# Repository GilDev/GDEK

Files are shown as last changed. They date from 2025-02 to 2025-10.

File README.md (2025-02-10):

# GDEK: Your first ergonomic keyboard

Want to try ergonomic keyboards? Don’t know where to start? Don’t want to break the bank yet before knowing what you really want? This may be the keyboard for you.

I created this keyboard following [a little crowdfunding campaign](https://fr.ulule.com/clavier-ergonomique-gildev/) I ran for people that were interested in improving their typing comfort but didn’t want to spend too much money on a device they might not like or would like some feature. This keyboard was entirely designed from scratch, after experimenting for some years with a TypeMatrix 2030, a original X-Bows (Kickstarter edition) and a personnal variant of the Sofle Choc RGB.

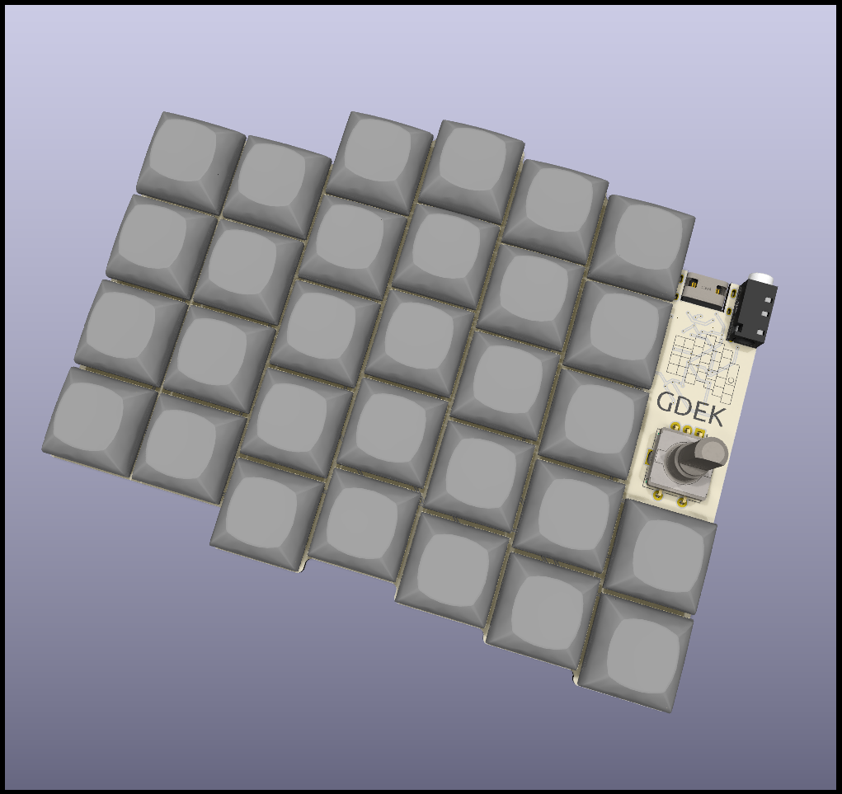
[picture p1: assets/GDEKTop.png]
GDEKTop


## Features

* **4×6 matrix**: you don’t risk missing anything, you can always disable things later on in software to see if missing that top number row would work for you. You can even type in [Bépo](https://bepo.fr/) with minimal modifications!
* **Split**: optimal hands placement, with room in the middle for a trackball or Magic Trackpad, and a simple audio cable to connect the two halves with connectors that won’t mechanically constrain your cable
* **Compact**: despite the “full” matrix, it’s easy to bring it along
* **5 keys thumb cluster**: enough for anything you could imagine
* **Supports MX, Kailh Choc and Gateron KS-33 low-profile switches**: I personnaly use KS-33 switches as they’re low-profile, cheap and support standard MX-compatible keycaps
* **Per-key RGB**: more than just for looks, they can indicate what some keys do, which layer you’re on, etc.
* **Encoder**: you may think it’s a gimmick, but at least you can try it and see if you like it. I love it to scroll, move the cursor, control volume, etc.
* **RP2040**: a very cool and powerful microcontroller that will support any features you could image without breaking a sweat. Easy to flash: it appears like a USB drive that you can drag the firmware onto
* **QMK firmware with VIA support**: easily configurable and customizable via a web app
* **Assembly-friendly**: send the PCB to be assembled and just solder the switches, encoders and audio TRS jack (pretty easy)
* **Open-source**: you can modify the design to your liking, design a case and so on

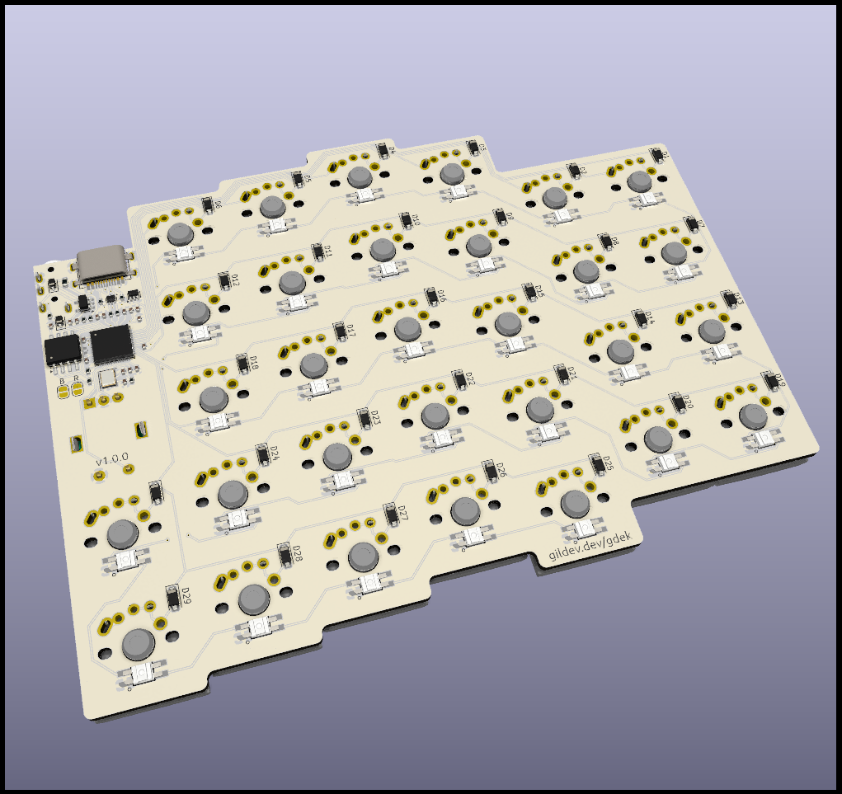
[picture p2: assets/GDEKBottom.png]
GDEKBottom


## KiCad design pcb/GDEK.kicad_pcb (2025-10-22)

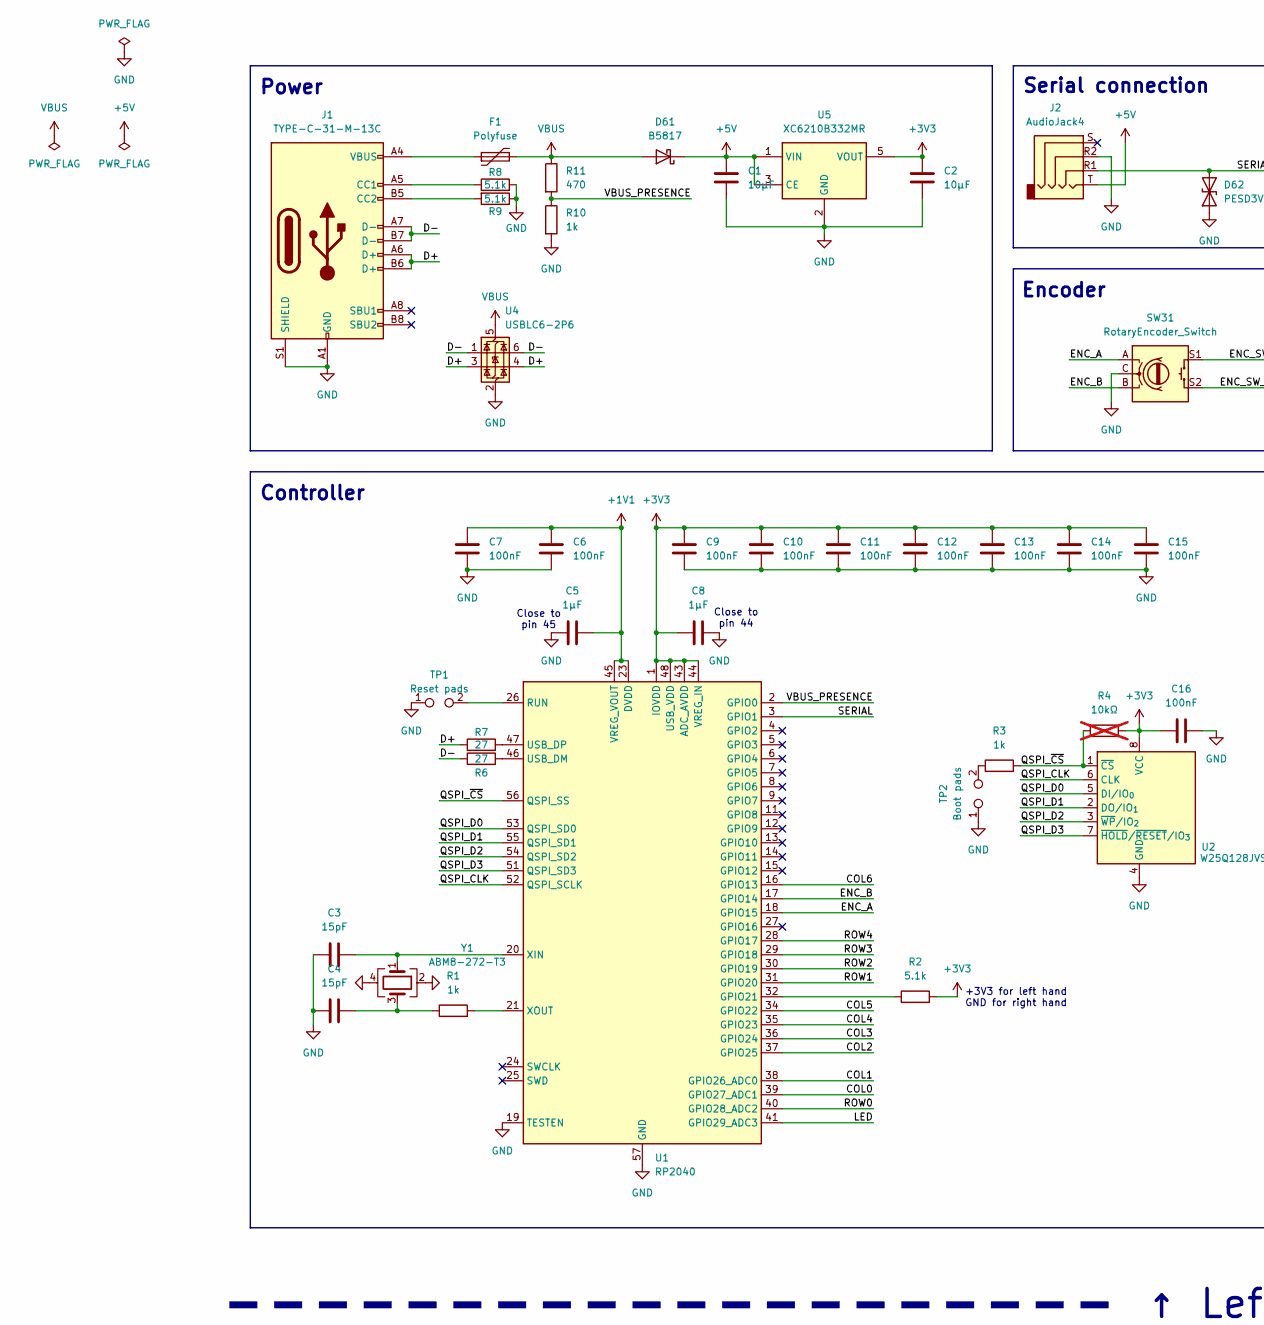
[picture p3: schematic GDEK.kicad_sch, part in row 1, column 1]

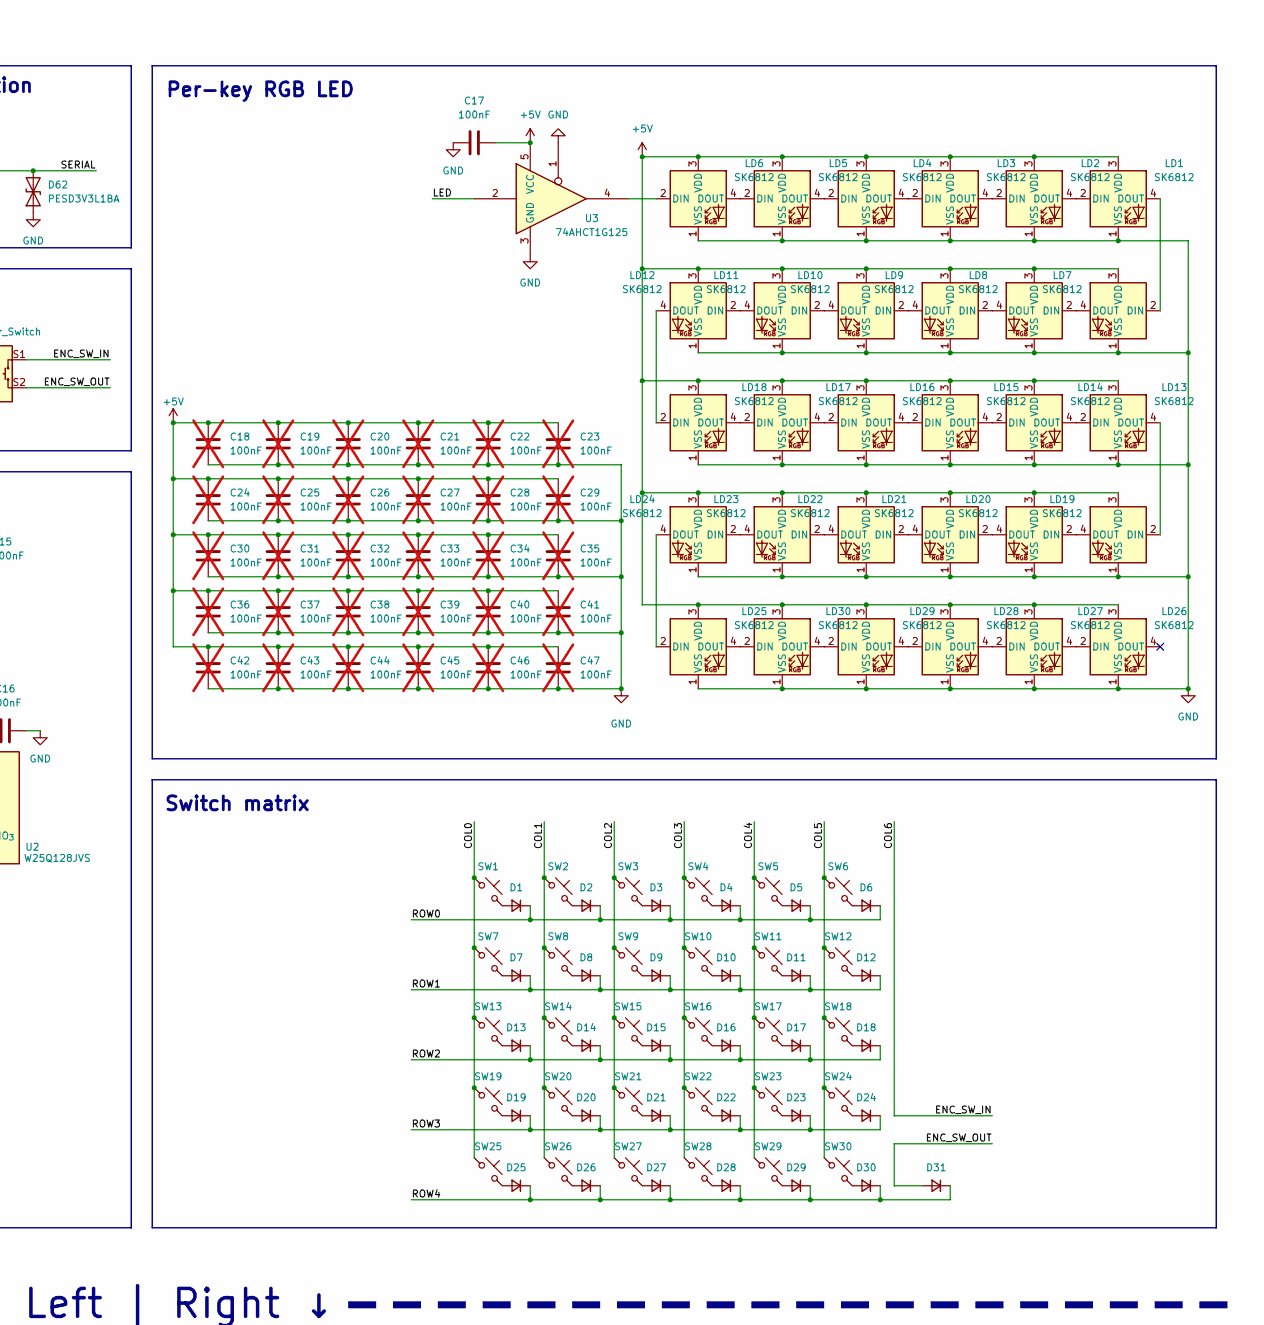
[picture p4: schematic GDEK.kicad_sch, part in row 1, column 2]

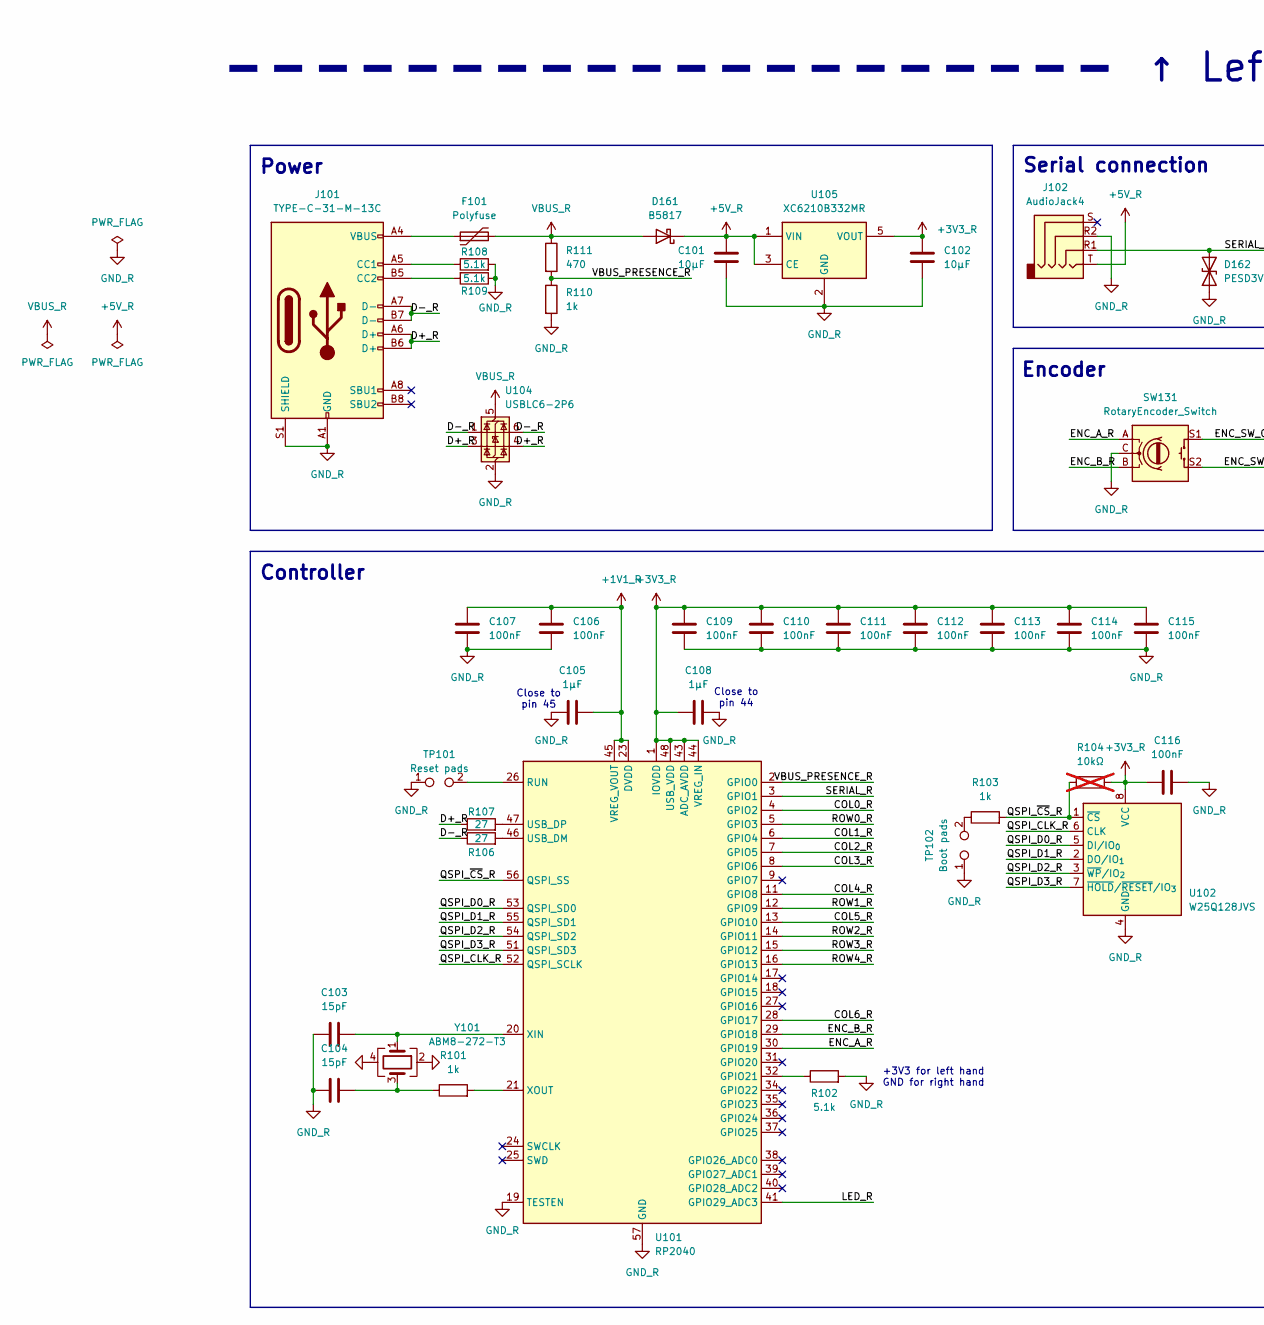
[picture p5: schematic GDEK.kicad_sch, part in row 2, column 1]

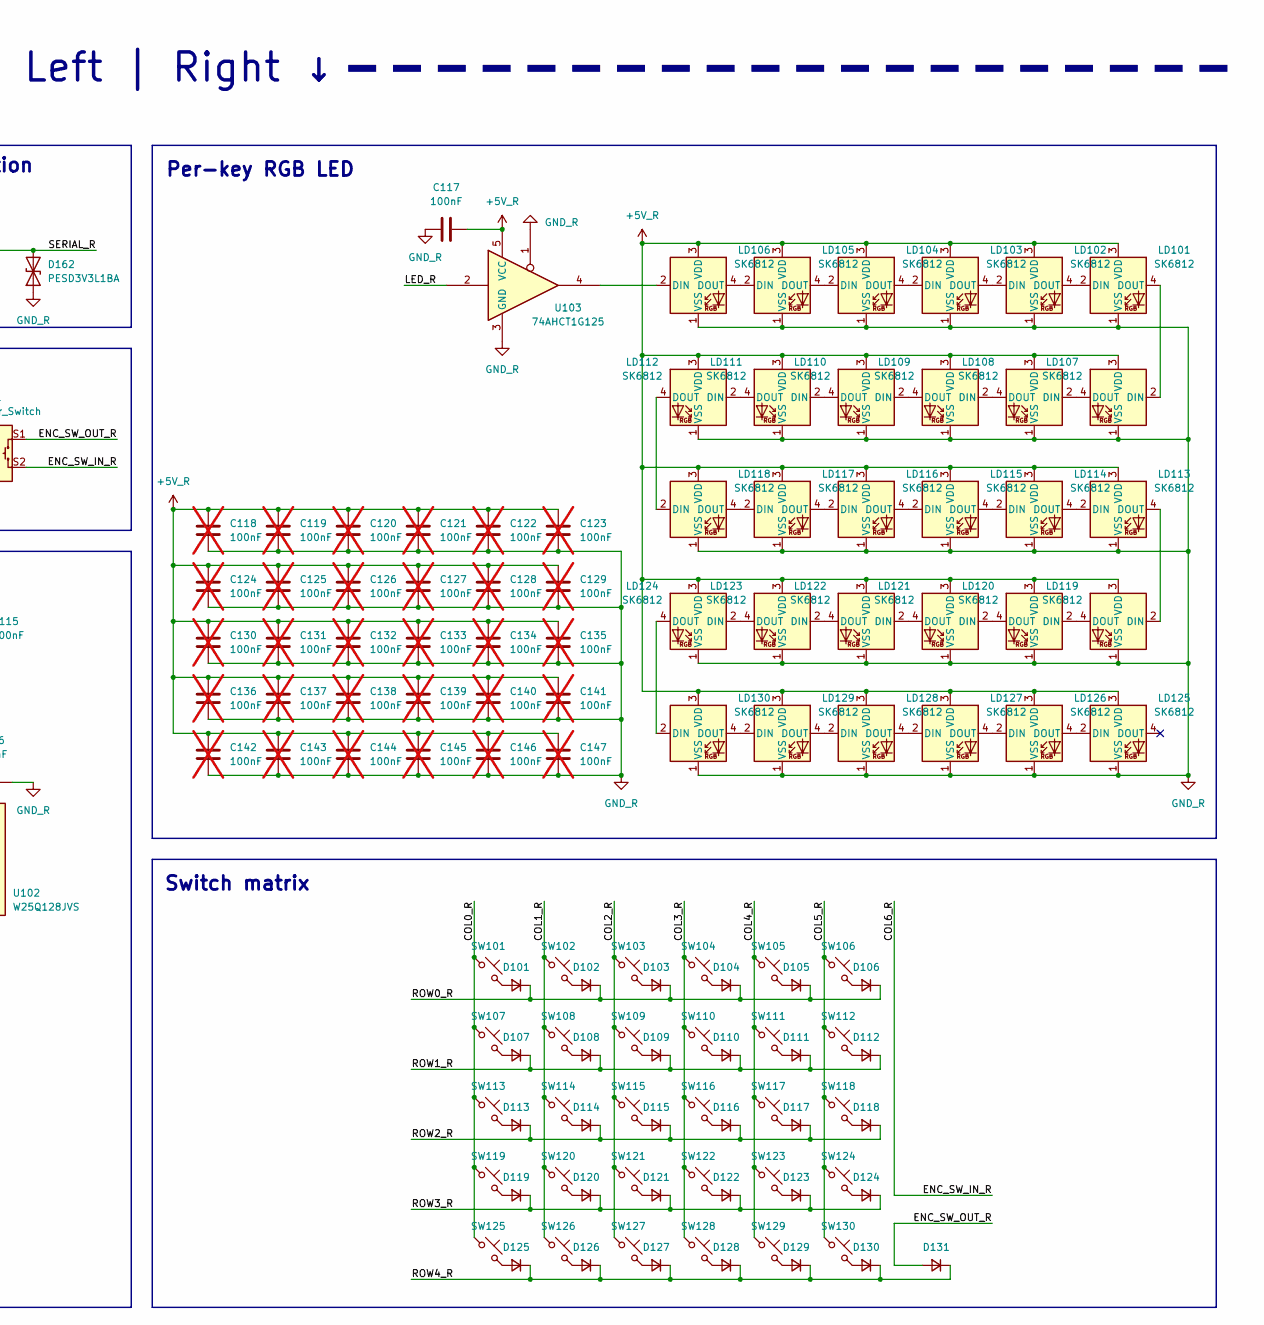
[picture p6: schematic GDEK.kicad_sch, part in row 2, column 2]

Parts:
C1, C2, C101, C102: 10µF; C_0402_1005Metric; LCSC C15525
C3, C4, C103, C104: 15pF; C_0402_1005Metric; LCSC C1548
C5, C8, C105, C108: 1µF; C_0402_1005Metric; LCSC C52923
C6, C7, C9, C10, C11, C12, C13, C14, C15, C16, C17, C106, C107, C109, C110, C111, C112, C113, C114, C115, C116, C117: 100nF; C_0402_1005Metric; LCSC C1525
C18, C19, C20, C21, C22, C23, C24, C25, C26, C27, C28, C29, C30, C31, C32, C33, C34, C35, C36, C37, C38, C39, C40, C41, C42, C43, C44, C45, C46, C47, C118, C119, C120, C121, C122, C123, C124, C125, C126, C127, C128, C129, C130, C131, C132, C133, C134, C135, C136, C137, C138, C139, C140, C141, C142, C143, C144, C145, C146, C147: 100nF; C_0402_1005Metric; LCSC C1525; not fitted
D1, D2, D3, D4, D5, D6, D7, D8, D9, D10, D11, D12, D13, D14, D15, D16, D17, D18, D19, D20, D21, D22, D23, D24, D25, D26, D27, D28, D29, D30, D31, D101, D102, D103, D104, D105, D106, D107, D108, D109, D110, D111, D112, D113, D114, D115, D116, D117, D118, D119, D120, D121, D122, D123, D124, D125, D126, D127, D128, D129, D130, D131: D_Small; D_SOD-123; LCSC C7420318
D61, D161: B5817; D_SOD-323; LCSC C123899
D62, D162: PESD3V3L1BA; D_SOD-323; LCSC C2827682
F1, F101: Polyfuse; Fuse_0603_1608Metric; LCSC C69679
J1, J101: TYPE-C-31-M-13C; USB_C_Receptacle_HRO_TYPE-C-31-M-13B; LCSC C2848620
J2, J102: AudioJack4; AUDIO-TH_PJ-320A-4P-DIP; LCSC C18185602
LD1, LD2, LD3, LD4, LD5, LD6, LD7, LD8, LD9, LD10, LD11, LD12, LD13, LD14, LD15, LD16, LD17, LD18, LD19, LD20, LD21, LD22, LD23, LD24, LD25, LD26, LD27, LD28, LD29, LD30, LD101, LD102, LD103, LD104, LD105, LD106, LD107, LD108, LD109, LD110, LD111, LD112, LD113, LD114, LD115, LD116, LD117, LD118, LD119, LD120, LD121, LD122, LD123, LD124, LD125, LD126, LD127, LD128, LD129, LD130: SK6812; SK6812MINIE; LCSC C5149201
R1, R3, R10, R101, R103, R110: 1k; R_0402_1005Metric; LCSC C11702
R2, R8, R9, R102, R108, R109: 5.1k; R_0402_1005Metric; LCSC C25905
R4, R104: 10kΩ; R_0402_1005Metric; not fitted
R6, R7, R106, R107: 27; R_0402_1005Metric; LCSC C25100
R11, R111: 470; R_0402_1005Metric; LCSC C25117
SW1, SW2, SW3, SW4, SW5, SW6, SW7, SW8, SW9, SW10, SW11, SW12, SW13, SW14, SW15, SW16, SW17, SW18, SW19, SW20, SW21, SW22, SW23, SW24, SW25, SW26, SW27, SW28, SW29, SW30, SW101, SW102, SW103, SW104, SW105, SW106, SW107, SW108, SW109, SW110, SW111, SW112, SW113, SW114, SW115, SW116, SW117, SW118, SW119, SW120, SW121, SW122, SW123, SW124, SW125, SW126, SW127, SW128, SW129, SW130: SW_Push_45deg; MX+KailhChoc+GateronKS_Tight
SW31, SW131: RotaryEncoder_Switch; RotaryEncoder_Alps_EC11E-Switch_Vertical_H20mm
TP1, TP101: Reset pads; SolderJumper-2_P1.3mm_Open_RoundedPad1.0x1.5mm
TP2, TP102: Boot pads; SolderJumper-2_P1.3mm_Open_RoundedPad1.0x1.5mm
U1, U101: RP2040; QFN-56-1EP_7x7mm_P0.4mm_EP3.2x3.2mm; LCSC C2040
U2, U102: W25Q128JVS; SOIC-8_5.3x5.3mm_P1.27mm; LCSC C97521
U3, U103: 74AHCT1G125; SOT-353_SC-70-5; LCSC C151417
U4, U104: USBLC6-2P6; SOT-666; LCSC C2827693
U5, U105: XC6210B332MR; SOT-23-5
Y1, Y101: ABM8-272-T3; Crystal_SMD_3225-4Pin_3.2x2.5mm; LCSC C20625731

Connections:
+1V1: C5.2, C6.1, C7.1, U1.23 (DVDD), U1.45 (VREG_VOUT), U1.50 (DVDD)
+1V1_R: C105.2, C106.1, C107.1, U101.23 (DVDD), U101.45 (VREG_VOUT), U101.50 (DVDD)
+3V3: C2.1, C8.1, C9.1, C10.1, C11.1, C12.1, C13.1, C14.1, C15.1, C16.1, R2.2, R4.2, U1.1 (IOVDD), U1.10 (IOVDD), U1.22 (IOVDD), U1.33 (IOVDD), U1.42 (IOVDD), U1.43 (ADC_AVDD), U1.44 (VREG_IN), U1.48 (USB_VDD), U1.49 (IOVDD), U2.8 (VCC), U5.5 (VOUT)
+3V3_R: C102.1, C108.1, C109.1, C110.1, C111.1, C112.1, C113.1, C114.1, C115.1, C116.1, R104.1, U101.1 (IOVDD), U101.10 (IOVDD), U101.22 (IOVDD), U101.33 (IOVDD), U101.42 (IOVDD), U101.43 (ADC_AVDD), U101.44 (VREG_IN), U101.48 (USB_VDD), U101.49 (IOVDD), U102.8 (VCC), U105.5 (VOUT)
+5V: C1.1, C17.2, C18.2, C19.2, C20.2, C21.2, C22.2, C23.2, C24.2, C25.2, C26.2, C27.2, C28.2, C29.2, C30.2, C31.2, C32.2, C33.2, C34.2, C35.2, C36.2, C37.2, C38.2, C39.2, C40.2, C41.2, C42.2, C43.2, C44.2, C45.2, C46.2, C47.2, D61.1 (K), J2.T, LD1.3 (VDD), LD2.3 (VDD), LD3.3 (VDD), LD4.3 (VDD), LD5.3 (VDD), LD6.3 (VDD), LD7.3 (VDD), LD8.3 (VDD), LD9.3 (VDD), LD10.3 (VDD), LD11.3 (VDD), LD12.3 (VDD), LD13.3 (VDD), LD14.3 (VDD), LD15.3 (VDD), LD16.3 (VDD), LD17.3 (VDD), LD18.3 (VDD), LD19.3 (VDD), LD20.3 (VDD), LD21.3 (VDD), LD22.3 (VDD), LD23.3 (VDD), LD24.3 (VDD), LD25.3 (VDD), LD26.3 (VDD), LD27.3 (VDD), LD28.3 (VDD), LD29.3 (VDD), LD30.3 (VDD), U3.5 (VCC), U5.1 (VIN), U5.3 (CE)
+5V_R: C101.1, C117.2, C118.2, C119.2, C120.2, C121.2, C122.2, C123.2, C124.2, C125.2, C126.2, C127.2, C128.2, C129.2, C130.2, C131.2, C132.2, C133.2, C134.2, C135.2, C136.2, C137.2, C138.2, C139.2, C140.2, C141.2, C142.2, C143.2, C144.2, C145.2, C146.2, C147.2, D161.1 (K), J102.T, LD101.3 (VDD), LD102.3 (VDD), LD103.3 (VDD), LD104.3 (VDD), LD105.3 (VDD), LD106.3 (VDD), LD107.3 (VDD), LD108.3 (VDD), LD109.3 (VDD), LD110.3 (VDD), LD111.3 (VDD), LD112.3 (VDD), LD113.3 (VDD), LD114.3 (VDD), LD115.3 (VDD), LD116.3 (VDD), LD117.3 (VDD), LD118.3 (VDD), LD119.3 (VDD), LD120.3 (VDD), LD121.3 (VDD), LD122.3 (VDD), LD123.3 (VDD), LD124.3 (VDD), LD125.3 (VDD), LD126.3 (VDD), LD127.3 (VDD), LD128.3 (VDD), LD129.3 (VDD), LD130.3 (VDD), U103.5 (VCC), U105.1 (VIN), U105.3 (CE)
/COL0: SW1.1, SW7.1, SW13.1, SW19.1, SW25.1, U1.39 (GPIO27_ADC1)
/COL0_R: SW101.1, SW107.1, SW113.1, SW119.1, SW125.1, U101.4 (GPIO2)
/COL1: SW2.1, SW8.1, SW14.1, SW20.1, SW26.1, U1.38 (GPIO26_ADC0)
/COL1_R: SW102.1, SW108.1, SW114.1, SW120.1, SW126.1, U101.6 (GPIO4)
/COL2: SW3.1, SW9.1, SW15.1, SW21.1, SW27.1, U1.37 (GPIO25)
/COL2_R: SW103.1, SW109.1, SW115.1, SW121.1, SW127.1, U101.7 (GPIO5)
/COL3: SW4.1, SW10.1, SW16.1, SW22.1, SW28.1, U1.36 (GPIO24)
/COL3_R: SW104.1, SW110.1, SW116.1, SW122.1, SW128.1, U101.8 (GPIO6)
/COL4: SW5.1, SW11.1, SW17.1, SW23.1, SW29.1, U1.35 (GPIO23)
/COL4_R: SW105.1, SW111.1, SW117.1, SW123.1, SW129.1, U101.11 (GPIO8)
/COL5: SW6.1, SW12.1, SW18.1, SW24.1, SW30.1, U1.34 (GPIO22)
/COL5_R: SW106.1, SW112.1, SW118.1, SW124.1, SW130.1, U101.13 (GPIO10)
/COL6: SW31.S1, U1.16 (GPIO13)
/COL6_R: SW131.S2, U101.28 (GPIO17)
/D+: J1.A6 (D+), J1.B6 (D+), R7.1, U4.3 (I/O2), U4.4 (I/O2)
/D+_R: J101.A6 (D+), J101.B6 (D+), R107.1, U104.3 (I/O2), U104.4 (I/O2)
/D-: J1.A7 (D-), J1.B7 (D-), R6.1, U4.1 (I/O1), U4.6 (I/O1)
/D-_R: J101.A7 (D-), J101.B7 (D-), R106.1, U104.1 (I/O1), U104.6 (I/O1)
/ENC_A: SW31.A, U1.18 (GPIO15)
/ENC_A_R: SW131.A, U101.30 (GPIO19)
/ENC_B: SW31.B, U1.17 (GPIO14)
/ENC_B_R: SW131.B, U101.29 (GPIO18)
/ENC_SW_OUT: D31.2 (A), SW31.S2
/ENC_SW_OUT_R: D131.2 (A), SW131.S1
/LED: U1.41 (GPIO29_ADC3), U3.2
/LED_R: U101.41 (GPIO29_ADC3), U103.2
/QSPI_CLK: U1.52 (QSPI_SCLK), U2.6 (CLK)
/QSPI_CLK_R: U101.52 (QSPI_SCLK), U102.6 (CLK)
/QSPI_D0: U1.53 (QSPI_SD0), U2.5 (DI/IO_{0})
/QSPI_D0_R: U101.53 (QSPI_SD0), U102.5 (DI/IO_{0})
/QSPI_D1: U1.55 (QSPI_SD1), U2.2 (DO/IO_{1})
/QSPI_D1_R: U101.55 (QSPI_SD1), U102.2 (DO/IO_{1})
/QSPI_D2: U1.54 (QSPI_SD2), U2.3 (~WP/IO_{2})
/QSPI_D2_R: U101.54 (QSPI_SD2), U102.3 (~WP/IO_{2})
/QSPI_D3: U1.51 (QSPI_SD3), U2.7 (~HOLD/~RESET/IO_{3})
/QSPI_D3_R: U101.51 (QSPI_SD3), U102.7 (~HOLD/~RESET/IO_{3})
/QSPI_~CS: R3.2, R4.1, U1.56 (QSPI_SS), U2.1 (~CS)
/QSPI_~CS_R: R103.2, R104.2, U101.56 (QSPI_SS), U102.1 (~CS)
/ROW0: D1.1 (K), D2.1 (K), D3.1 (K), D4.1 (K), D5.1 (K), D6.1 (K), U1.40 (GPIO28_ADC2)
/ROW0_R: D101.1 (K), D102.1 (K), D103.1 (K), D104.1 (K), D105.1 (K), D106.1 (K), U101.5 (GPIO3)
/ROW1: D7.1 (K), D8.1 (K), D9.1 (K), D10.1 (K), D11.1 (K), D12.1 (K), U1.31 (GPIO20)
/ROW1_R: D107.1 (K), D108.1 (K), D109.1 (K), D110.1 (K), D111.1 (K), D112.1 (K), U101.12 (GPIO9)
/ROW2: D13.1 (K), D14.1 (K), D15.1 (K), D16.1 (K), D17.1 (K), D18.1 (K), U1.30 (GPIO19)
/ROW2_R: D113.1 (K), D114.1 (K), D115.1 (K), D116.1 (K), D117.1 (K), D118.1 (K), U101.14 (GPIO11)
/ROW3: D19.1 (K), D20.1 (K), D21.1 (K), D22.1 (K), D23.1 (K), D24.1 (K), U1.29 (GPIO18)
/ROW3_R: D119.1 (K), D120.1 (K), D121.1 (K), D122.1 (K), D123.1 (K), D124.1 (K), U101.15 (GPIO12)
/ROW4: D25.1 (K), D26.1 (K), D27.1 (K), D28.1 (K), D29.1 (K), D30.1 (K), D31.1 (K), U1.28 (GPIO17)
/ROW4_R: D125.1 (K), D126.1 (K), D127.1 (K), D128.1 (K), D129.1 (K), D130.1 (K), D131.1 (K), U101.16 (GPIO13)
/SERIAL: D62.2 (A2), J2.R1, U1.3 (GPIO1)
/SERIAL_R: D162.2 (A2), J102.R1, U101.3 (GPIO1)
/VBUS_PRESENCE: R10.1, R11.2, U1.2 (GPIO0)
/VBUS_PRESENCE_R: R110.1, R111.2, U101.2 (GPIO0)
GND: C1.2, C2.2, C3.1, C4.1, C5.1, C6.2, C7.2, C8.2, C9.2, C10.2, C11.2, C12.2, C13.2, C14.2, C15.2, C16.2, C17.1, C18.1, C19.1, C20.1, C21.1, C22.1, C23.1, C24.1, C25.1, C26.1, C27.1, C28.1, C29.1, C30.1, C31.1, C32.1, C33.1, C34.1, C35.1, C36.1, C37.1, C38.1, C39.1, C40.1, C41.1, C42.1, C43.1, C44.1, C45.1, C46.1, C47.1, D62.1 (A1), J1.A1 (GND), J1.A12 (GND), J1.B1 (GND), J1.B12 (GND), J1.S1 (SHIELD), J2.R2, LD1.1 (VSS), LD2.1 (VSS), LD3.1 (VSS), LD4.1 (VSS), LD5.1 (VSS), LD6.1 (VSS), LD7.1 (VSS), LD8.1 (VSS), LD9.1 (VSS), LD10.1 (VSS), LD11.1 (VSS), LD12.1 (VSS), LD13.1 (VSS), LD14.1 (VSS), LD15.1 (VSS), LD16.1 (VSS), LD17.1 (VSS), LD18.1 (VSS), LD19.1 (VSS), LD20.1 (VSS), LD21.1 (VSS), LD22.1 (VSS), LD23.1 (VSS), LD24.1 (VSS), LD25.1 (VSS), LD26.1 (VSS), LD27.1 (VSS), LD28.1 (VSS), LD29.1 (VSS), LD30.1 (VSS), R8.2, R9.1, R10.2, SW31.C, TP1.1, TP2.1, U1.19 (TESTEN), U1.57 (GND), U2.4 (GND), U3.1, U3.3 (GND), U4.2 (GND), U5.2 (GND), Y1.2, Y1.4; also elsewhere on the board
GND_R: C101.2, C102.2, C103.1, C104.1, C105.1, C106.2, C107.2, C108.2, C109.2, C110.2, C111.2, C112.2, C113.2, C114.2, C115.2, C116.2, C117.1, C118.1, C119.1, C120.1, C121.1, C122.1, C123.1, C124.1, C125.1, C126.1, C127.1, C128.1, C129.1, C130.1, C131.1, C132.1, C133.1, C134.1, C135.1, C136.1, C137.1, C138.1, C139.1, C140.1, C141.1, C142.1, C143.1, C144.1, C145.1, C146.1, C147.1, D162.1 (A1), J101.A1 (GND), J101.A12 (GND), J101.B1 (GND), J101.B12 (GND), J101.S1 (SHIELD), J102.R2, LD101.1 (VSS), LD102.1 (VSS), LD103.1 (VSS), LD104.1 (VSS), LD105.1 (VSS), LD106.1 (VSS), LD107.1 (VSS), LD108.1 (VSS), LD109.1 (VSS), LD110.1 (VSS), LD111.1 (VSS), LD112.1 (VSS), LD113.1 (VSS), LD114.1 (VSS), LD115.1 (VSS), LD116.1 (VSS), LD117.1 (VSS), LD118.1 (VSS), LD119.1 (VSS), LD120.1 (VSS), LD121.1 (VSS), LD122.1 (VSS), LD123.1 (VSS), LD124.1 (VSS), LD125.1 (VSS), LD126.1 (VSS), LD127.1 (VSS), LD128.1 (VSS), LD129.1 (VSS), LD130.1 (VSS), R102.2, R108.2, R109.1, R110.2, SW131.C, TP101.1, TP102.1, U101.19 (TESTEN), U101.57 (GND), U102.4 (GND), U103.1, U103.3 (GND), U104.2 (GND), U105.2 (GND), Y101.2, Y101.4; also elsewhere on the board
unnamed: C4.2, R1.1, Y1.3
unnamed: C104.2, R101.1, Y101.3
unnamed: D1.2 (A), SW1.2
unnamed: D2.2 (A), SW2.2
unnamed: D3.2 (A), SW3.2
unnamed: D4.2 (A), SW4.2
unnamed: D5.2 (A), SW5.2
unnamed: D6.2 (A), SW6.2
unnamed: D7.2 (A), SW7.2
unnamed: D8.2 (A), SW8.2
unnamed: D9.2 (A), SW9.2
unnamed: D10.2 (A), SW10.2
unnamed: D11.2 (A), SW11.2
unnamed: D12.2 (A), SW12.2
unnamed: D13.2 (A), SW13.2
unnamed: D14.2 (A), SW14.2
unnamed: D15.2 (A), SW15.2
unnamed: D16.2 (A), SW16.2
unnamed: D17.2 (A), SW17.2
unnamed: D18.2 (A), SW18.2
unnamed: D19.2 (A), SW19.2
unnamed: D20.2 (A), SW20.2
unnamed: D21.2 (A), SW21.2
unnamed: D22.2 (A), SW22.2
unnamed: D23.2 (A), SW23.2
unnamed: D24.2 (A), SW24.2
unnamed: D25.2 (A), SW25.2
unnamed: D26.2 (A), SW26.2
unnamed: D27.2 (A), SW27.2
unnamed: D28.2 (A), SW28.2
unnamed: D29.2 (A), SW29.2
unnamed: D30.2 (A), SW30.2
unnamed: D101.2 (A), SW101.2
unnamed: D102.2 (A), SW102.2
unnamed: D103.2 (A), SW103.2
unnamed: D104.2 (A), SW104.2
unnamed: D105.2 (A), SW105.2
unnamed: D106.2 (A), SW106.2
unnamed: D107.2 (A), SW107.2
unnamed: D108.2 (A), SW108.2
unnamed: D109.2 (A), SW109.2
unnamed: D110.2 (A), SW110.2
unnamed: D111.2 (A), SW111.2
unnamed: D112.2 (A), SW112.2
unnamed: D113.2 (A), SW113.2
unnamed: D114.2 (A), SW114.2
unnamed: D115.2 (A), SW115.2
unnamed: D116.2 (A), SW116.2
unnamed: D117.2 (A), SW117.2
unnamed: D118.2 (A), SW118.2
unnamed: D119.2 (A), SW119.2
unnamed: D120.2 (A), SW120.2
unnamed: D121.2 (A), SW121.2
unnamed: D122.2 (A), SW122.2
unnamed: D123.2 (A), SW123.2
unnamed: D124.2 (A), SW124.2
unnamed: D125.2 (A), SW125.2
unnamed: D126.2 (A), SW126.2
unnamed: D127.2 (A), SW127.2
unnamed: D128.2 (A), SW128.2
unnamed: D129.2 (A), SW129.2
unnamed: D130.2 (A), SW130.2
unnamed: F1.1, J1.A4 (VBUS), J1.A9 (VBUS), J1.B4 (VBUS), J1.B9 (VBUS)
unnamed: F101.1, J101.A4 (VBUS), J101.A9 (VBUS), J101.B4 (VBUS), J101.B9 (VBUS)
unnamed: J1.A5 (CC1), R8.1
unnamed: J1.B5 (CC2), R9.2
unnamed: J101.A5 (CC1), R108.1
unnamed: J101.B5 (CC2), R109.2
unnamed: LD1.2 (DIN), LD2.4 (DOUT)
unnamed: LD1.4 (DOUT), LD7.2 (DIN)
unnamed: LD2.2 (DIN), LD3.4 (DOUT)
unnamed: LD3.2 (DIN), LD4.4 (DOUT)
unnamed: LD4.2 (DIN), LD5.4 (DOUT)
unnamed: LD5.2 (DIN), LD6.4 (DOUT)
unnamed: LD6.2 (DIN), U3.4
unnamed: LD7.4 (DOUT), LD8.2 (DIN)
unnamed: LD8.4 (DOUT), LD9.2 (DIN)
unnamed: LD9.4 (DOUT), LD10.2 (DIN)
unnamed: LD10.4 (DOUT), LD11.2 (DIN)
unnamed: LD11.4 (DOUT), LD12.2 (DIN)
unnamed: LD12.4 (DOUT), LD18.2 (DIN)
unnamed: LD13.2 (DIN), LD14.4 (DOUT)
unnamed: LD13.4 (DOUT), LD19.2 (DIN)
unnamed: LD14.2 (DIN), LD15.4 (DOUT)
unnamed: LD15.2 (DIN), LD16.4 (DOUT)
unnamed: LD16.2 (DIN), LD17.4 (DOUT)
unnamed: LD17.2 (DIN), LD18.4 (DOUT)
unnamed: LD19.4 (DOUT), LD20.2 (DIN)
unnamed: LD20.4 (DOUT), LD21.2 (DIN)
unnamed: LD21.4 (DOUT), LD22.2 (DIN)
unnamed: LD22.4 (DOUT), LD23.2 (DIN)
unnamed: LD23.4 (DOUT), LD24.2 (DIN)
unnamed: LD24.4 (DOUT), LD25.2 (DIN)
unnamed: LD25.4 (DOUT), LD30.2 (DIN)
unnamed: LD26.2 (DIN), LD27.4 (DOUT)
unnamed: LD27.2 (DIN), LD28.4 (DOUT)
unnamed: LD28.2 (DIN), LD29.4 (DOUT)
unnamed: LD29.2 (DIN), LD30.4 (DOUT)
unnamed: LD101.2 (DIN), LD102.4 (DOUT)
unnamed: LD101.4 (DOUT), LD107.2 (DIN)
unnamed: LD102.2 (DIN), LD103.4 (DOUT)
unnamed: LD103.2 (DIN), LD104.4 (DOUT)
unnamed: LD104.2 (DIN), LD105.4 (DOUT)
unnamed: LD105.2 (DIN), LD106.4 (DOUT)
unnamed: LD106.2 (DIN), U103.4
unnamed: LD107.4 (DOUT), LD108.2 (DIN)
unnamed: LD108.4 (DOUT), LD109.2 (DIN)
unnamed: LD109.4 (DOUT), LD110.2 (DIN)
unnamed: LD110.4 (DOUT), LD111.2 (DIN)
unnamed: LD111.4 (DOUT), LD112.2 (DIN)
unnamed: LD112.4 (DOUT), LD118.2 (DIN)
unnamed: LD113.2 (DIN), LD114.4 (DOUT)
unnamed: LD113.4 (DOUT), LD119.2 (DIN)
unnamed: LD114.2 (DIN), LD115.4 (DOUT)
unnamed: LD115.2 (DIN), LD116.4 (DOUT)
unnamed: LD116.2 (DIN), LD117.4 (DOUT)
unnamed: LD117.2 (DIN), LD118.4 (DOUT)
unnamed: LD119.4 (DOUT), LD120.2 (DIN)
unnamed: LD120.4 (DOUT), LD121.2 (DIN)
unnamed: LD121.4 (DOUT), LD122.2 (DIN)
unnamed: LD122.4 (DOUT), LD123.2 (DIN)
unnamed: LD123.4 (DOUT), LD124.2 (DIN)
unnamed: LD124.4 (DOUT), LD130.2 (DIN)
unnamed: LD125.2 (DIN), LD126.4 (DOUT)
unnamed: LD126.2 (DIN), LD127.4 (DOUT)
unnamed: LD127.2 (DIN), LD128.4 (DOUT)
unnamed: LD128.2 (DIN), LD129.4 (DOUT)
unnamed: LD129.2 (DIN), LD130.4 (DOUT)
unnamed 188: R3.1, TP2.2; also elsewhere on the board
unnamed 189: R103.1, TP102.2; also elsewhere on the board
unnamed: R2.1, U1.32 (GPIO21)
unnamed 191: TP1.2, U1.26 (RUN); also elsewhere on the board
unnamed: R6.2, U1.46 (USB_DM)
unnamed: R7.2, U1.47 (USB_DP)
unnamed: C3.2, U1.20 (XIN), Y1.1
unnamed: R1.2, U1.21 (XOUT)
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

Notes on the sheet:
Close to pin 44
Power
+3V3 for left hand GND for right hand
Per-key RGB LED
Switch matrix
Serial connection
Close to pin 45
Controller
Encoder
↑ Left | Right ↓

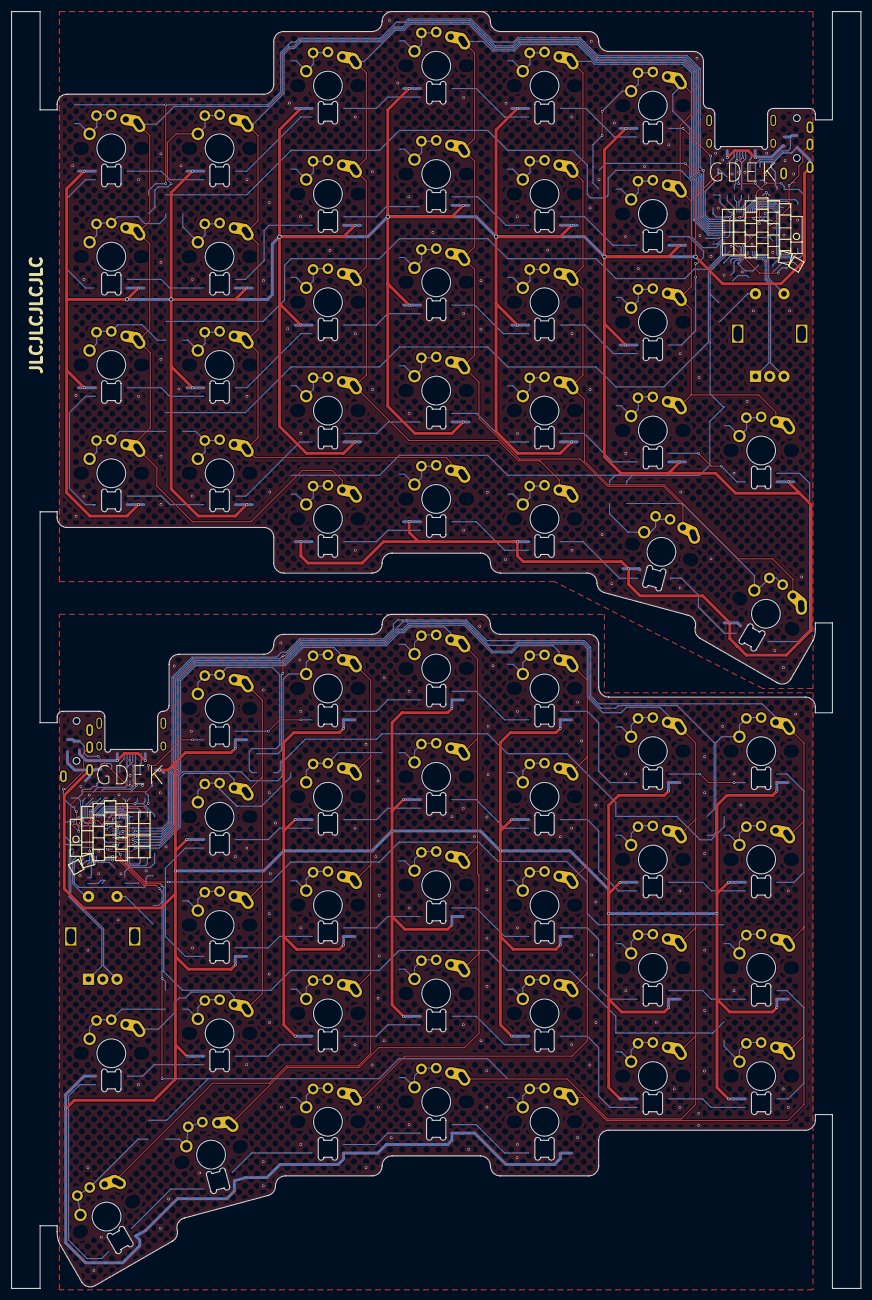
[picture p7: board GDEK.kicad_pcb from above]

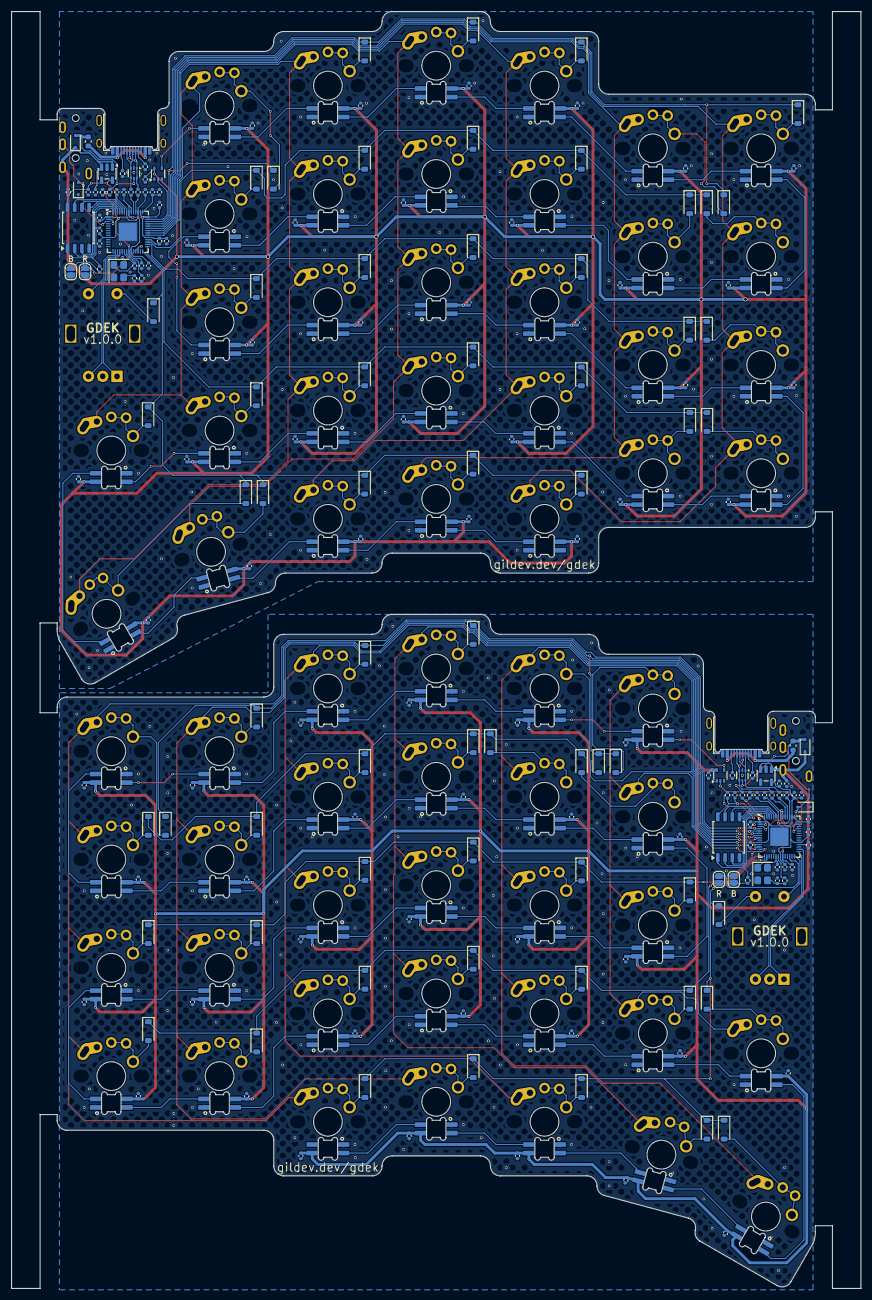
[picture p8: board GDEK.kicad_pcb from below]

Board: 2 copper layers, 149.0 x 224.0 mm, 324 parts (260 on the bottom side), 204 nets.

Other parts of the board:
B: Boot pads; SolderJumper-2_P1.3mm_Open_RoundedPad1.0x1.5mm
B#2: Boot pads; SolderJumper-2_P1.3mm_Open_RoundedPad1.0x1.5mm
R: Reset pads; SolderJumper-2_P1.3mm_Open_RoundedPad1.0x1.5mm
R#2: Reset pads; SolderJumper-2_P1.3mm_Open_RoundedPad1.0x1.5mm

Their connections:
GND: B.1, R.1; also elsewhere on the board
GND_R: B#2.1, R#2.1; also elsewhere on the board
unnamed 188: B.2; also elsewhere on the board
unnamed 189: B#2.2; also elsewhere on the board
unnamed 191: R.2; also elsewhere on the board
unnamed 197: R#2.2; also elsewhere on the board

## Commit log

2025-02-08 🎉 Initial commit
    [GDEK.kicad_pcb, GDEK.kicad_sch]
2025-02-09 ♻️ Make switch symbol multi-unit for switch and LED
    Also changes VBUS_PRESENCE voltage divider’s resistors and handedness pull-up/down resistor in order to remove one reference (10kΩ).
    [GDEK.kicad_sch]
2025-02-09 🔧 Finish footprint assignments
    [GDEK.kicad_sch]
2025-02-10 ✨ Finish left hand PCB
    [GDEK.kicad_pcb, GDEK.kicad_sch]
2025-02-10 📝 Add 3D renders to README
2025-02-16 ✨ Add optional decoupling for each LED
    [GDEK.kicad_sch]
2025-03-16 ♻️ Split and improve switch and LED footprints
    Tighter tolerances and split so that PCBA isn’t getting confused by the footprint having both components on top (switch) and bottom (LED).
2025-03-16 ♻️ Replace LED and reroute them
    They are flipped on odd rows to have a better layout not requiring any layer switch because of the new LED footprint with mouse ears.
    [GDEK.kicad_pcb, GDEK.kicad_sch]
2025-04-02 ✨ Update lots of stuff (and make the thumb cluster round)
    [GDEK.kicad_pcb, GDEK.kicad_sch]
2025-04-02 ✨ Finish board outline
    Fix thumb cluster’s rounded corners. Add rounded corners near connectors. Add milled slots for USB-C connector’s corners.
    [GDEK.kicad_pcb]
2025-04-05 ✨ Route LED power and decoupling
    [GDEK.kicad_pcb, GDEK.kicad_sch]
2025-04-05 ⏪️ Put the USB connector back down (recessed)
    Because most cables used with the keyboard will be straights (and not right angled), I prefer to just recess the connector and keep 2 mm margin on each side for the male connector to fit in. That makes the PCB more rigid overall (compared to having that 2 mm-wide finger for the through-hole pads of the connector), but of course prevents the use of most right-angled connectors.
    [GDEK.kicad_pcb]
2025-04-06 🔧 Refine board constraints and components positions
    I think this time is the one! The encoder will be able to accept 20 mm knobs which I feel are better to use.
2025-04-06 🐛 Fix matrix traces
    Had to be moved because of the outline change on the top right switch.
2025-04-13 ✨ Route LED power rails
    [GDEK.kicad_sch]
2025-04-13 🚨 Fix all DRC issues!
    For real! Still have to check clearance to board outline later on, mostly for the jack connector’s pads.
    Other half can probably be started now! Or maybe I try to make this one reversible, that would be cool, but required two-sides assembly because of the LEDs.
    This evening was pretty productive, good night!
2025-04-14 ✨ Add tooling holes for assembly
2025-04-14 ✨ Add hatch pattern on planes
2025-04-14 🎨 Clean up planes
2025-04-14 ➕ Add missing encoder footprint
    Hide silkscreen.
2025-04-14 ✨ Add order number on PCB (hidden)
2025-04-16 ✨ Start right hand (outline and switch placement done)
2025-04-16 ✨ Right hand: place encoder and connectors
2025-04-16 🚧 Place LEDs
    [GDEK.kicad_pcb]
2025-04-17 ✨ Right hand: place diodes
    [GDEK.kicad_pcb]
2025-04-17 ✨ Right hand: finish LEDs positioning
    [GDEK.kicad_pcb]
2025-04-17 ✨ Right hand: place decoupling capacitors of LEDs
    [GDEK.kicad_pcb]
2025-04-19 🎨 Set all capacitors in the same orientation
    There was one remaining horizontal one.
    [GDEK.kicad_pcb]
2025-04-19 🎨 Remove component references from silkscreen
    YOLO.
    [GDEK.kicad_pcb]
2025-04-20 ⚰️ Remove debug pins
    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
    [GDEK.kicad_sch]
2025-04-21 ✨ Route right hand (except encoder)
    Getting late! Will hopefully finish tomorrow. Then DRC, then panelization with vcuts, then order!
    [GDEK.kicad_sch]
2025-04-21 ✨ Finish routing of right hand!
    Finally! No DRC error!
    [GDEK.kicad_sch]
2025-04-21 ♻️ Change board outline for v-cut panelization
2025-04-23 ✨ Add tooling rails
    Required for a PCBA of a big number of board.
2025-04-23 ⚡️ Improve ground planes fill
2025-04-23 ✨ Add v-cuts on User.1 layer
2025-04-23 🎨 Mode order number to tooling edge
2025-04-25 ✨ Mirror silkscreen
2025-04-25 🎨 Add encoder 3D model
    First embedded model, that’s cool!
    [GDEK.kicad_sch]
2025-04-25 🔧 Adjust copper to board edge clearance
    It’s not perfect, it’s 0.05 mm but the v-cut edges have a 0.4 mm clearance in order to avoid having teared copper planes. Can’t do much more it seems otherwise the Type-C port and LED pads are quite far away from the edge, and milling apparently doesn’t cause issues with copper planes.
2025-04-25 🎨 Move vias out of silkscreen as much as possible
2025-04-25 ⚡️ Update fiducials and vias
2025-04-27 ⚡️ Improve vias placement
2025-04-27 🔖 Bump version to v1.0.0
    [GDEK.kicad_sch]
2025-04-27 🐛 Fix BOM
    Type-C footprint was wrong on right half.
2025-04-29 ⚡️ Flip right hand
    Reduces panel length by ~15 mm. 149×224 mm total.
2025-04-29 📦️ Add missing 3D model of LED
2025-09-24 🔥 Remove protection resistor on serial line
    This prevents communication between halves because of the high impedance of the MCU’s GPIO which makes a low level at a voltage too high to be registered as low.
    [GDEK.kicad_sch]
2025-09-24 🔧 Make switches center holes a tad bigger
    Two cents bigger. Hopefully the switches are still properly maintained but without having to force too much to insert them all at the same time (using my little soldering tool).
2025-09-24 🎨 Hide traces under inner thumb key and improve ground planes
2025-09-29 ✨ Rearrange some diodes on the right hand
    So that silicone feet can be installed as close to the edge as possible.
2025-09-29 ✨ Rearrange some diodes on the left hand
    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
2025-09-30 ♻️ Put the encoders’ switches on the matrix
    Required if I want to be able to remap it using VIA or Vial. Yeah it’s a bummer…
    Also fixed all DRC issues (updated standard footprints and reduced courtyard’s size of SK6812MINI-E because of the slightly bigger switches’ holes).
    [GDEK.kicad_sch]
2025-10-01 🔧 Make LED hole a tad smaller
    The part between this hole and the switch’s hole is already pretty thin, making the switch’s hole bigger makes it even thinner, so I reduced the hole’s height by two cents (going from ~0.27 mm to ~0.25 mm tolerance, shouldn’t be an issue for manufacturing).
    Also adjusted a few vias and ran DRC again.
2025-10-01 🔧 Move some diodes a bit
2025-10-17 ⬆️ Update standard footprints
2025-10-22 🔧 Make LED hole a tad smaller
    Manufacturing files didn’t change so I made the hole 0.05 mm bigger instead of 0.02 mm bigger, hopefully that is somehow reflected in the output files but I’m not entirely sure…
    It was 5 mm at first, now 5.05. I think 5.1 would be too big, it just fits right now, but the JLCPCB tolerances are apparently 0.2 mm so maybe I got lucky on the first two prototype batches…
    [GDEK.kicad_pcb]
